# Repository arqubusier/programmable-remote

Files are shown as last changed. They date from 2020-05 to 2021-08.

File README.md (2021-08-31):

# Get project

git clone  --recurse-submodules git@github.com:arqubusier/programmable-remote.git

# Build using docker

    $ cd <project-root>

Build docker image like so:

    $ docker build -t stm32-cpp-bare .

Run the container:

    $ docker run -it --name stm32-cpp-bare -p 4444:4444 -v "$(pwd)":/usr/src/app --privileged -v /dev/bus/usb:/dev/bus/usb stm32-cpp-bare /bin/bash

If you stop the container, you can start it again with:

    $ docker start -a -i stm32-cpp-bare

The project root directory on the host machine and "/usr/src/app" in the container can be used to share data.

## First-time setup

In the container run:

  root@mycontainer $ make -C libopencm3

## Build

In the container run:

  root@mycontainer $ make -C src

## Flashing

This project is currently only tested for the "bluepill" devboard.
In the container run:

  root@mycontainer $ openocd -f bluepill.cfg -c "program src/programmable-remote.elf verify reset exit"

## compile and flash using running openocd server

Start openocd server

  root@mycontainer openocd -f bluepill.cfg
  
Build and flash:

DOES NOT WORK
  root@mycontainer make -C src && echo "program src/programmable-remote.elf verify reset" | telnet localhost 4444
  
  reset halt
  stm32f1x mass_erase 0
  flash write_bank 0 src/programmable-remote.bin 0
  reset halt
  
## Write protection error

Solve using 

  reset halt; stm32f1x unlock 0

## Debug with openocd and gdb

  root@mycontainer gdb-multiarch -tui --eval-command="target remote localhost:3333" src/programmable-remote.elf

## Generate compile_commands.json

  $ make -C src clean
  $ bear make -C src

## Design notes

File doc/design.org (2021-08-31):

* Todo
** TODO Ir sensor wrong orientation
** TODO Ir sensor footprint mark direction
** TODO SWD Silkscreen pin marking
** TODO No dip switch use solder bridge instead
** TODO lower profile crystal
** TODO Reset switch wrong pinout
** TODO Battery holder pads match battery holder placement better
** TODO Battery holder battery too tight
** TODO Transistor swap pins
** TODO Bad ir range
** TODO pcb remote not working with AV reciever
* Design
** General algorihm
Assume protocol has a series of bursts.
For sensing, store length of every burst and space.

*** Determine length of message
Must not confuse message with repeat message.

Timeout: assume time limit for section (burst or space)
< 23.939 ms for NEC2 (All ones)
24/0.005 = 48000

Limit on number of sections.

** interfaces summary

See schema

** Programs
4 programs 0-9
10 commands
100 segments 16 bit (How are these stored? 32-bit aligned?)
4*1000*2B = 8 KB
Packing could reduce it

** Recording

Use a timer, diff-timer, to measure pulse lengths.
When triggered follow sensing algorithm based on state machine.
Compare elapsed duration since previous trigger and evaluate expected duration based on current state.
If evaluation fails, goto backoff state of algorithm.
Restart timer.

Detect overlflow by checking UIF bit in TIMx_SR, URS bit must be set correctly.

** Timers

- inter segment (inter command) tim5
- carrier tim4, tim4_ch1  pb6 (remap==0)
- debounce tim3

Total time = (counter*prescaler)/SYSCLK frequency
prescaler = (total time*SYSCLK frequency)/countermax

*** Pulse lengths
- Sequence timer
- command timer (maybe reprogram sequence timer on the fly)
- carrier timer

16bit prescaler
16bit counter

16bit counter 2^16-1 = 65535

RCC 72MHz
ABP1 Max 36Mhz

*** Command input handling

min period 9ms (start bit)
max period Nec2, address all ones: 
9000 + 4500 + 16*2250 + 16*(2250+1120)/2 + 560 [us] = 77020 [us] ~ 77 ms

choose value closer to longest required pulse: 9 ms (NEC)
20 ms.

prescaler = 20ms * 72 MHz/65535 = 21.97
period = 22/72Mhz

set prescaler to 22 -> timeout slightly larger than 20ms
65535*(22/72Mhz) = 0.0200245833... s

1st = 9000 us ~ 29455
2nd = 4500 us ~ 14727
short pulse = 560 us, 560e-6/(22/(72e6)) = 560*72/22 ~ 1833 counter
long pulse = (2250-560) us = 1690,  1690*72/22 ~ 5531 counter

Start timer when ir sensor goes low. Then stop when goes high and save value.
Interrupt on sensing pin.
Start timer on falling edge interrupt, Stop timer and read value on rising endge interrupt.

*** Carrier frequency

To keep the phase of the carrier pulse, start timer at beginning of command and keep it running until the end.
Control the carrier pulse output by enabling/disabling the output.
A separate timer is used for the carrier pulse.

38kHz ca 0.23 us
Use toggle output of timer.
The output toggles at double frequency 76Khz.
Use approximation for the period
0.013157894736842105263157894736842105263157894736842105263... ms
13.157894736842105263157894736842105263157894736842105263... us

use no prescaler for max resolution
0.0000131578947*72000000 = 947.3684184
947/72000000 = 1.3152777777777778e-05

Use upcounting mode TIMx_CR1, TIMx_CR2
Use continuous mode (not One-pulse mode)
autoreload 947 TIMx_ARR, TIMx_CR1, TIMx_CR2
compare 947 TIMx_CCRx, disable preload OCxPE bit in the TIMx_CCMRx register
output toggle mode, OCxM bits in the TIMx_CCMRx register (OCxM=011)
disable interrupt (CCXIE bit in the TIMx_DIER register)
disable dma (CCxDE bit in the TIMx_DIER register)
**** TODO Use TIM1 for higher precision? 72Mhz vs 36Mhz
     Cannot get it to work.
works for TIM2 and TIM3.
Tim1 uses ABP2 Different config needed?
Tim1 has extra features? which? different config needed?

*** Button debounce timer

bounce ca 5ms

SYSCLK 36 mhz (?)   

prescaler = 5ms * 72 MHz/65535 = 5.4...   

set prescaler to 6 ->
counter = 5ms * 72 MHz/6 = 60'000

*** Transmit inter command

Reuse Command timer.

set prescaler to 23 -> timeout approx 110 ms
65535*(121/72Mhz) = 0.11013520833333335 s

If this time is too short, a receiving device might ignore it and/or think it is part and/or think it is part of the previous command.

Test appropriate value.

** Buttons

0-9
ok
back

* Knowledge
** IR Protocols
diode frequencies:

longest pulse: 9ms (NEC)
*** PWM-based

http://irdb.tk/find/

**** NEC
38kHz
8 bit address, 8 bit inverse address, 8bit command, 8bit inverse command
https://techdocs.altium.com/display/FPGA/NEC+Infrared+Transmission+Protocol
**** NEC2
38kHz
https://www.sbprojects.net/knowledge/ir/nec.php
16 bit address, 16bit command

**** Epson projector
38kHz
Protocol NEC2
**** Harman Kardon
38kHz
Harman Kardon Receivers: Protocol Emerson device 40 subdevice -1
Harman Kardon Receivers: Protocol NEC device 128 subdevice 112
Harman Kardon Receivers: Protocol NEC1 device 4 subdevice -1
Harman Kardon Receivers: Protocol NEC1 device 128 subdevice 112
Harman Kardon Receivers: Protocol NEC1 device 130 subdevice 114
Harman Kardon Receivers: Protocol NEC1 device 132 subdevice 66
Harman Kardon Receivers: Protocol NEC1 device 132 subdevice 116
Harman Kardon Receivers: Protocol NEC1 device 134 subdevice 118
Harman Kardon Receivers: Protocol NEC2 device 128 subdevice 112
Harman Kardon Receivers: Protocol NEC2 device 130 subdevice 114
Harman Kardon Receivers: Protocol NEC2 device 164 subdevice -1
Harman Kardon Receivers: Protocol Pioneer device 130 subdevice 114
Harman Kardon Receivers: Protocol Pioneer device 161 subdevice -1
Harman Kardon Receivers: Protocol RCA-38 device 7 subdevice -1

** Remotes
*** Harman Kardon
carrier 587 us - 560us

OK 7484 6f90

**** osd menu

0-7   k k k l k k k k  0100  4 
8-15  k k k k k k k l  0001  1
16-23 k k k l k k k k  0100  4
24-31 k l k l k l k k  1110  E
32-39 k k k k k l k l  0011  3
40-47 k l k k k l k k  1010  a
48-55 k l k l k k k k  1100  c
56-63 k k k l k k k l  0101  5

NEC1
OK 0x12 e2 90 6F
18 226

NEC2
OK 0xe212  6F90

*** Epson
carrier 587 us - 625 us
*** OSSC
carrier 562 us - 612 us
** Components
*** Stm32f103c8t6
**** Constraints
***** Memory
stm32f103c8t6

SRAM 10KiB
Flash 64KiB

**** Clock

Three sources: internal, external, pll. Pll uses internal or external as a source and can multiply the frequency.
Max sysclock for internal is 36mHz, max for external is 72 MHz. 

Default seems to be 36mHz -> internal?

*** IR diode
*** IR receiver
https://www.electrokit.com/uploads/productfile/41015/41015734_-_IR_Receiver_Module.pdf
negative and signal marked on board, middle is vcc 0.4v-4.4v.
**** TSOP382
combined led and "demodulator", turns 38
  
Program ir sequences using sensed signals from existisng remote.
Use a button combination to enter programming mode.
Use the following algorithm to create a program.

DRAW DIAGRAM.
1. Press programming button. leds start flashinsg to indicate programming mode.
   press number to select slot and continue.
2. Press a button on other remote to select command.
   Leds indicate success/failure.
   Use stop sequence to stop.
   The current program will be stored and a default value
3. Enter repeate count. Use reset button to clear. Use confirm button to proceed.
4. Press stop sequence to finish, otherwise Go to step 2

Sens signals from remote when programming.

*** Serial EEPROM
*** Buttons
*** display
*** leds
** IR NEC Timings

Bit Pulse length 560us



./necsequence.png

Max duration 100 ms, repeat distance.
Min 560us

* DONE Weird timings_ values                                        :ARCHIVE:
prescaler 360:
$96 = {796, 897, 118, 109, 118, 109, 118, 334, 118, 109, 112, 114, 118, 109, 113, 114, 113, 339, 118, 109, 118, 109, 112, 340, 113, 114, 113, 340, 113, 340, 113, 340, 118, 108, 118, 108, 112, 114, 118, 109, 118, 108, 118, 334, 113, 114, 117, 109, 113, 340, 113, 340, 117, 335, 112, 340, 113, 340, 113, 114, 112, 340, 113, 340, 113, 114, 113, 0 <repeats 33 times>}

prescaler 180: 
p timings_
$92 = {577, 797, 235, 214, 235, 215, 225, 676, 234, 215, 235, 215, 235, 215, 234, 215, 224, 676, 235, 216, 234, 215, 225, 676, 234, 216, 224, 677, 225, 676, 224, 677, 234, 215, 235, 216, 234, 215, 235, 215, 235, 215, 224, 676, 235, 215, 235, 215, 224, 676, 224, 676, 224, 677, 224, 676, 224, 676, 235, 216, 224, 676, 224, 676, 235, 215, 224, 0 <repeats 33 times>}

prescaler 100:
$95 = {416, 200, 422, 384, 420, 384, 399, 212, 401, 404, 420, 384, 400, 405, 401, 403, 420, 191, 419, 387, 400, 405, 399, 212, 418, 386, 399, 211, 400, 211, 400, 211, 400, 405, 400, 406, 418, 386, 417, 386, 419, 384, 399, 211, 400, 404, 399, 405, 400, 210, 399, 211, 400, 212, 420, 190, 419, 194, 401, 405, 400, 210, 420, 192, 421, 384, 399, 0 <repeats 33 times>}

Had not set period, so counter was looping to early.
* TODO Synchronize Multiple interrupts and main thread.             :ARCHIVE:

Use interrupt priorities.

We have main thread and a number of interrupts:

- input_ir exti input_handler
- delay timer
- output_ir timer

- button exti
  - select between input/output modes.
    - only enable either:
      - output_ir timer and delay timer or
      - input_ir timer and delay timer

set delay timer lower prio, can still be tail-chained

delay timer can come first, then be preempted

* TODO Button circuit                                               :ARCHIVE:
10 buttons

** direct conncetion: 10 gpio internal pulldown, 1 common high connection.
*** TODO interrupt handling
possible to use same isr for multiple gpios?

Use exti1-10 for each button, one isr per button.

debouncing: use general synchronization method, interrupt disabling.
** Keypad
** Swithes

* Problems
** TODO Figure out why this basic calculation yields wrong result

  uint32_t b  = (rcc_apb1_frequency * 2);

**TODO Hangs in constructor : ARCHIVE :

    in statemachine.hpp : 52 command_index_{0},
    program_index_{program_index} {}

calls memcpy and hangs in loop 0x08004198-0x080041a2

Dump of assembler code for function memcpy:
   0x0800418a <+0>:	add	r2, r1
;
r0 0x200000d8 536871128;
r1 0x200027e8 536881128;
r2 0x20004fd4 536891348 0x0800418c < +2 > : cmp r1,
    r2 = > 0x0800418e < +4 > : add.w r3, r0, #4294967295;
0xffffffff destination address;
r3 0x200000d7 536871127 0x08004192 < +8 > : bne.n 0x8004196 < memcpy + 12 > ;
r4 0x200000d8 536871128;
lr 0x80019fd 134224381 0x08004194 < +10 > : bx lr 0x08004196 < +12 > : push {
  r4, lr
}
0x08004198 < +14 > : ldrb.w r4, [r1], #1;
postincrement r1 0x0800419c < +18 > : cmp r1, r2 0x0800419e < +20 > : strb.w r4,
    [ r3, #1 ] !;
preincrement r3 0x080041a2 < +24 > : bne.n 0x8004198 < memcpy + 14 >
    0x080041a4 < +26 > : pop{r4, pc}

                         memcpy 536891348 -
                         536881128 10220 elements 2 * 100 * 10 *
                             5

                             does it fit in destination
    ? ;
r3 0x200000d7 536871127 536871127 +
    10219 = 536881346 = 0x200028c2 0x200000d7 - 0x200028c2 > 0x200027e8

                        too many bytes
    ? src,
    return addresses cause problems
    ?

    hard_faults,
    CFSR == 0x20000 user fault,
    invalid state.no idea why.

        (gdb)p
        / x pc $22 = 0x8001ae9 Uneven address
    ? ? ?

        ***Soloution Redesign,
    global variable,
    or pass around reference to common state instead of composition.

            global variable
            + easy to implement + can still change it in test
            - hidden state **Following hangs
    : ARCHIVE
    :

    using Buttons = std::array<util::Io, kNumButtons>;
// global variable
// note double outer braces
// if single outer braces are used the problem disappears
constexpr Buttons buttons{{
    {GPIOA, GPIO1},
}};

for (const auto &button : buttons) {
  uint32_t exti{util::GetExtiIrqn(button.pin_).value()};
}

** Debounce timer works for tim3 but not tim5                       :ARCHIVE:

commit 8a56048e89eca8753037eba329801153a9f771ca

*** Solution

stm32f103c8t6 only has timers 1-4

* Example

** osd/menu harman cardon

 {
  prog_i = 0, cmd = {
    data_ = {_M_elems = {29462, 14780, 1844, 1841,
                         1838,  1841,  1836, 5550,
                         1844,  1839,  1838, 1838,
                         1836,  1841,  1837, 1841,
                         1833,  5548,  1845, 1842,
                         1839,  1840,  1837, 5549,
                         1838,  1841,  1836, 5551,
                         1839,  5548,  1838, 5551,
                         1840,  1839,  1835, 5548,
                         1839,  5554,  1837, 5548,
                         1842,  1841,  1834, 5553,
                         1836,  5552,  1835, 5551,
                         1841,  1843,  1835, 1842,
                         1838,  1840,  1836, 1839,
                         1834,  5555,  1839, 1837,
                         1838,  1840,  1836, 1842,
                         1833,  5549,  1837, 0 < repeats 33 times > }},
    size = 67
  }

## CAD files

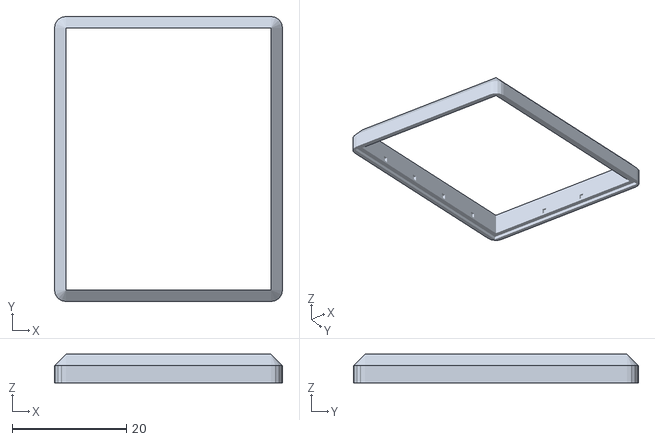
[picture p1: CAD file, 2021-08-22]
case/xcsg/remote.stl
40.0 x 50.0 x 5.00

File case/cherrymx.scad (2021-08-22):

switch_side_outer=19.1;
switch_sep = 19.05;
switch_side_inner=13.6;
switch_height=3;
plate_thick_d=0;
plate_thick=1.5 + plate_thick_d;
inset_h=switch_height - plate_thick;
inset_w=5;
inset_d=0.7;
outset_d=0.2;
switch_pcb_to_plate_top = 4.7;

module inset() {
    translate([0, switch_side_inner/2 + inset_d/2, (switch_height)/2 -inset_h - plate_thick])
        cube([inset_w, inset_d, 2*inset_h], center=true);
}

module outset() {
    translate([0, switch_side_inner/2 - outset_d/2, switch_height/2-plate_thick/2])
        difference() {
            cube([inset_w,outset_d,plate_thick], center=true);
            cube([inset_w-2.5,outset_d,plate_thick], center=true);
        }
}

module switch_pos(height=switch_height, center_height=false) {
    if (center_height) {
        cube([switch_side_outer, switch_side_outer, height], center=true);
    } else {
        translate([0, 0, height/2])
            cube([switch_side_outer, switch_side_outer, height], center=true);
    }
}

module SwitchPos2D() {
       square(switch_side_outer, center=true);
}

module SwitchNeg2D() {
       square(switch_side_inner, center=true);
}

module switch_neg_cube() {
    translate([0,0,switch_height/2])
        cube([switch_side_inner, switch_side_inner, switch_height], center=true);
}

module switch_neg(switch_height_mult=1) {
    translate([0,0,switch_height/2]) {
        difference() {
            cube([switch_side_inner, switch_side_inner, switch_height_mult*switch_height], center=true);
            *outset();
            *mirror([0,1,0])
                outset();
        }
        inset();
        mirror([0,1,0])
            inset();
    }
}

module switch(side_outer=switch_side_outer) {
    difference() {
        switch_pos(side_outer);
        switch_neg(1);
    }
}

module keycap(center=true) {
  cube([18, 18, 8.5],center=center);
}

function switch_corner_outer(offset, corner) = offset +
  ( (corner == "ne" ? [switch_side_outer/2, switch_side_outer/2, 0] :
     (corner == "se" ? [switch_side_outer/2, -switch_side_outer/2, 0] :
      (corner == "sw" ? [-switch_side_outer/2, -switch_side_outer/2, 0] :
       ([-switch_side_outer/2, switch_side_outer/2, 0])))) );

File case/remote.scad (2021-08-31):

include <cherrymx.scad>

$fn = 20;
module TriangleRightAngle(w, h) {
    polygon([[0,0], [w,0], [w,h]]);
}

module BoxChamfer(w,l,h,chamfer) {
    translate([chamfer,chamfer,0]) {
        minkowski() {
            cube([w-2*chamfer,l-2*chamfer,h-2*chamfer]);
            union() {
                translate([0,0,chamfer])
                    cylinder(h=chamfer, r1=chamfer, r2=0);
                cylinder(h=chamfer, r1=0, r2=chamfer);
            }
        }
    }
}

module BoxChamferTop(w,l,h,chamfer) {
    translate([chamfer,chamfer,0]) {
        minkowski() {
            cube([w-2*chamfer,l-2*chamfer,h-chamfer]);
            cylinder(h=chamfer, r1=chamfer, r2=0.4);
        }
    }
}

module BoxFilletSides(x, y, z, chamfer) {
    translate([chamfer,chamfer,0]) {
        minkowski() {
            cube([x-2*chamfer,y-2*chamfer,z-2*chamfer]);
            cylinder(h=chamfer, r=chamfer);
        }
    }
}


battery_y = 44+.5;
battery_d = 10;
battery_z = battery_d + 1.1;
battery_clip_x = 6.9 + .2;
battery_clip_y = .5 + .2;
battery_clip_plus_y = 2;
battery_clip_wall_thick = .8;
battery_clip_holder_y = battery_clip_plus_y + 2*battery_clip_wall_thick;
battery_holder_y = battery_y + 2*battery_clip_holder_y;
battery_holder_side_thick = 1;
battery_holder_x = 2*battery_d + battery_holder_side_thick;

module BatteryClipHolderNegative() {
    translate([0,.1,0]){
            rotate([90, 0, 0])
                cylinder(h= battery_clip_wall_thick+.2, d=battery_clip_x - 1);
            translate([battery_d, 0, 0])
                rotate([90, 0, 0])
                    cylinder(h= battery_clip_wall_thick+.2, d=battery_clip_x - 1);
    }
    
    translate([-battery_clip_x/2, -battery_clip_wall_thick-battery_clip_y, -battery_clip_x/2])
    {
        cube([battery_clip_x, battery_clip_y, battery_d]);
        translate([battery_d,0,0])
            cube([battery_clip_x, battery_clip_y, battery_d]);
    }
    
    translate([-battery_clip_x/2, -battery_clip_wall_thick-battery_clip_y, -battery_d/2]) {
        cube([battery_d + battery_clip_x, battery_clip_y, battery_d]);
    }
    
    translate([-battery_clip_y/2, -battery_clip_holder_y - battery_clip_wall_thick, -battery_clip_y + battery_d/2-1]) {
        cube([battery_clip_y,battery_clip_holder_y,battery_clip_y+1]);
        translate([battery_d, 0, 0])
            cube([battery_clip_y,battery_clip_holder_y,battery_clip_y+1]);
    }
    
    
    translate([-(battery_clip_x - 1)/2,-battery_clip_wall_thick - .1,0]) {
        cube([battery_clip_x - 1, battery_clip_wall_thick + .2, battery_d/2+1]);
        translate([battery_d, 0, 0])
            cube([battery_clip_x - 1, battery_clip_wall_thick + .2, battery_d/2+1]);
    }
}

module BatteryHolderNegative() {
    translate([battery_d/2, battery_clip_holder_y, battery_d/2]){
        rotate([-90, 0, 0])
            #cylinder(battery_y,d=battery_d);
        translate([battery_d, 0, 0])
            rotate([-90, 0, 0])
                cylinder(battery_y,d=battery_d);
        BatteryClipHolderNegative();
        translate([battery_d, battery_y, 0])
            rotate([0,0,180])
                BatteryClipHolderNegative();
     }

    translate([0,battery_clip_holder_y,battery_d/2])
        cube([2*battery_d, battery_y, battery_d]);
}

plate_thick = 2;
wall_thick = 2.7;
chamfer = 1.6;

pcb_y = 72.3;
pcb_x = switch_sep*2+ 2*2.7;
pcb_z = .8;
pcb_pos_z = 3.5 + plate_thick;
pcb_pos_y = wall_thick + battery_holder_y + 1;

switch_row0_pos_y = pcb_pos_y + 9 + switch_sep/2;


width_outer = pcb_x + 2*wall_thick;
width_inner = width_outer - 2*wall_thick;
height_high_inner = battery_z + plate_thick;
height_high_outer = height_high_inner + wall_thick;
height_low_outer = pcb_pos_z + pcb_z + 5.1;
height_low_inner = height_low_outer - wall_thick;

box1_outer_y = switch_row0_pos_y - switch_sep/2;
box1_inner_y = box1_outer_y - 2*wall_thick;

box2_outer_y = 3*switch_sep + 4*chamfer;
box2_inner_y = box2_outer_y - 2*wall_thick;
box2_pos_y = box1_outer_y - 2*chamfer;
box2_pos = [0, box2_pos_y, 0];

box3_inner_y = 3.8;
box3_outer_y = box3_inner_y + 2*wall_thick;
box3_pos = box2_pos + [0, box2_outer_y - 2*chamfer, 0];

outer_z = box2_pos_y+ box2_outer_y + box3_outer_y - 2*chamfer;
inner_z = outer_z - 2*wall_thick;

plate_lip_z = .6;
plate_lip_x = width_inner +2*.5;
plate_lip_y = inner_z +2*.5;

module BatteryHolder() {
    
    translate([wall_thick + battery_holder_x, wall_thick-battery_clip_wall_thick, height_high_inner])
        rotate([0,180,0])
        difference() {
            cube([battery_holder_x, battery_holder_y, battery_d]);
            translate([battery_holder_side_thick, 0, 0])
            BatteryHolderNegative();
        }
}

module ShellPositive() {
        BoxChamfer(width_outer, box1_outer_y, height_high_outer, chamfer);
        translate(box2_pos)
            BoxChamfer(width_outer, box2_outer_y, height_low_outer, chamfer);
        translate(box3_pos)
            BoxChamfer(width_outer, box3_outer_y, height_high_outer, chamfer);
}

module ShellNegative() {
    translate([wall_thick, wall_thick, -.1]) {
        BoxChamferTop(width_inner, box1_inner_y, height_high_inner, chamfer);
        translate(box2_pos + [0, -wall_thick*2, 0])
            BoxChamferTop(width_inner, box2_inner_y+wall_thick*4, height_low_inner, chamfer);
        translate(box3_pos)
            BoxChamferTop(width_inner, box3_inner_y, height_high_inner, chamfer);
    }
    
    translate([wall_thick, switch_row0_pos_y - switch_side_inner/2-7-1.2, pcb_pos_z + pcb_z])
        cube([width_inner, 7, 4]);
    translate([wall_thick, switch_row0_pos_y +2*switch_sep+ switch_side_inner/2+1.2, pcb_pos_z + pcb_z])
        cube([width_inner, 7, 4]);
}

niche_pos_z = 1.6;
niche_x = 3.2;
niche_y = 1.2;
niche_z = 1.2;
module Niche() {
    translate([0,0,niche_pos_z+niche_z/2])
        cube([niche_x, niche_y, niche_z], center=true);
}

module PlaceNiches() {
    nxs = [-9, 9];
    for (x = nxs) {
        translate([width_outer/2+x,wall_thick-niche_y/2+.1,0]) {
            rotate([0,0,180])
                children();
            translate([0, inner_z + niche_y -.2, 0])
                children();
        }
    }
    
    nys = [-45,-25, 0, 25, 45];
    for (y = nys) {
        translate([wall_thick-niche_y/2+.1,y+outer_z/2,0]) {
            rotate([0,0,90])
                children();
            translate([width_inner-.2+niche_y, 0, 0])
                rotate([0,0,-90])
                    children();
        }
    }
}

hook_x = niche_x - .2;
hook_y = niche_y;
hook_z = niche_z - .2;
module Hook() {
    translate([hook_x/2, -hook_y/2 -.2, niche_pos_z])
       rotate([0,-90,0])
        linear_extrude(hook_x)
            polygon([[0, 0], [hook_y, 0], [0,hook_z]]);
}




module Plate(clearance=0) {
    PlaceNiches()
        Hook();
    
    translate([wall_thick-clearance, wall_thick-clearance, 0])
        cube([width_inner+2*clearance, inner_z+2*clearance, plate_thick+clearance]);
   
    translate([wall_thick-.5-clearance, wall_thick -.5-clearance, 0])
        cube([plate_lip_x+2*clearance, plate_lip_y+2*clearance, plate_lip_z+clearance]);
}



ir_tx_x = 3.4;
ir_tx_rel_x = -3.8-ir_tx_x;
ir_rx_x = 6.6;
ir_rx_rel_x = 3.5;
module SensorHoles() {
    translate([width_outer/2, 2*chamfer + outer_z-1*wall_thick, pcb_pos_z + pcb_z]) {
        translate([ir_tx_rel_x, -.1, 0])
            rotate([90, 0, 0])
                BoxFilletSides(ir_rx_x, 2, 4, .5);
        translate([ir_rx_rel_x, 0, ir_tx_x/2])
            rotate([90, 0, 0])
                cylinder(h = 10, d=ir_tx_x);
        
    }
    led_hole_z = 20;
    led_hole_x = 2;
    #translate([width_outer/2+-led_hole_x/2, pcb_pos_y+pcb_y-3.4, height_high_outer - led_hole_z -.1]) {
        translate([-8.2,0,0])
            BoxFilletSides(led_hole_x,led_hole_x,led_hole_z,.5);
        translate([-10.8,0,0])
            BoxFilletSides(led_hole_x,led_hole_x,led_hole_z,.5);
    }  
}

module SwitchHoles() {
    translate ([width_outer/2-switch_sep/2, switch_row0_pos_y, height_low_outer - switch_height])
        for (col = [0:1]) {
            for (row = [0:2]) {
                translate([col*switch_sep, row*switch_sep, 0])
                    switch_neg(3);
            }
        }
}

module Pcb() {
    translate([wall_thick,pcb_pos_y,pcb_pos_z]) 
        cube([pcb_x, pcb_y, pcb_z]);
}

module Shell() {
    difference() {
        union() {
            difference() {
                ShellPositive();
                ShellNegative();
            }
            BatteryHolder();
        }

        SensorHoles();
        SwitchHoles();
        Plate(.2);
        PlaceNiches()
            Niche();
    }
}

//Shell();
//Pcb();
Plate();

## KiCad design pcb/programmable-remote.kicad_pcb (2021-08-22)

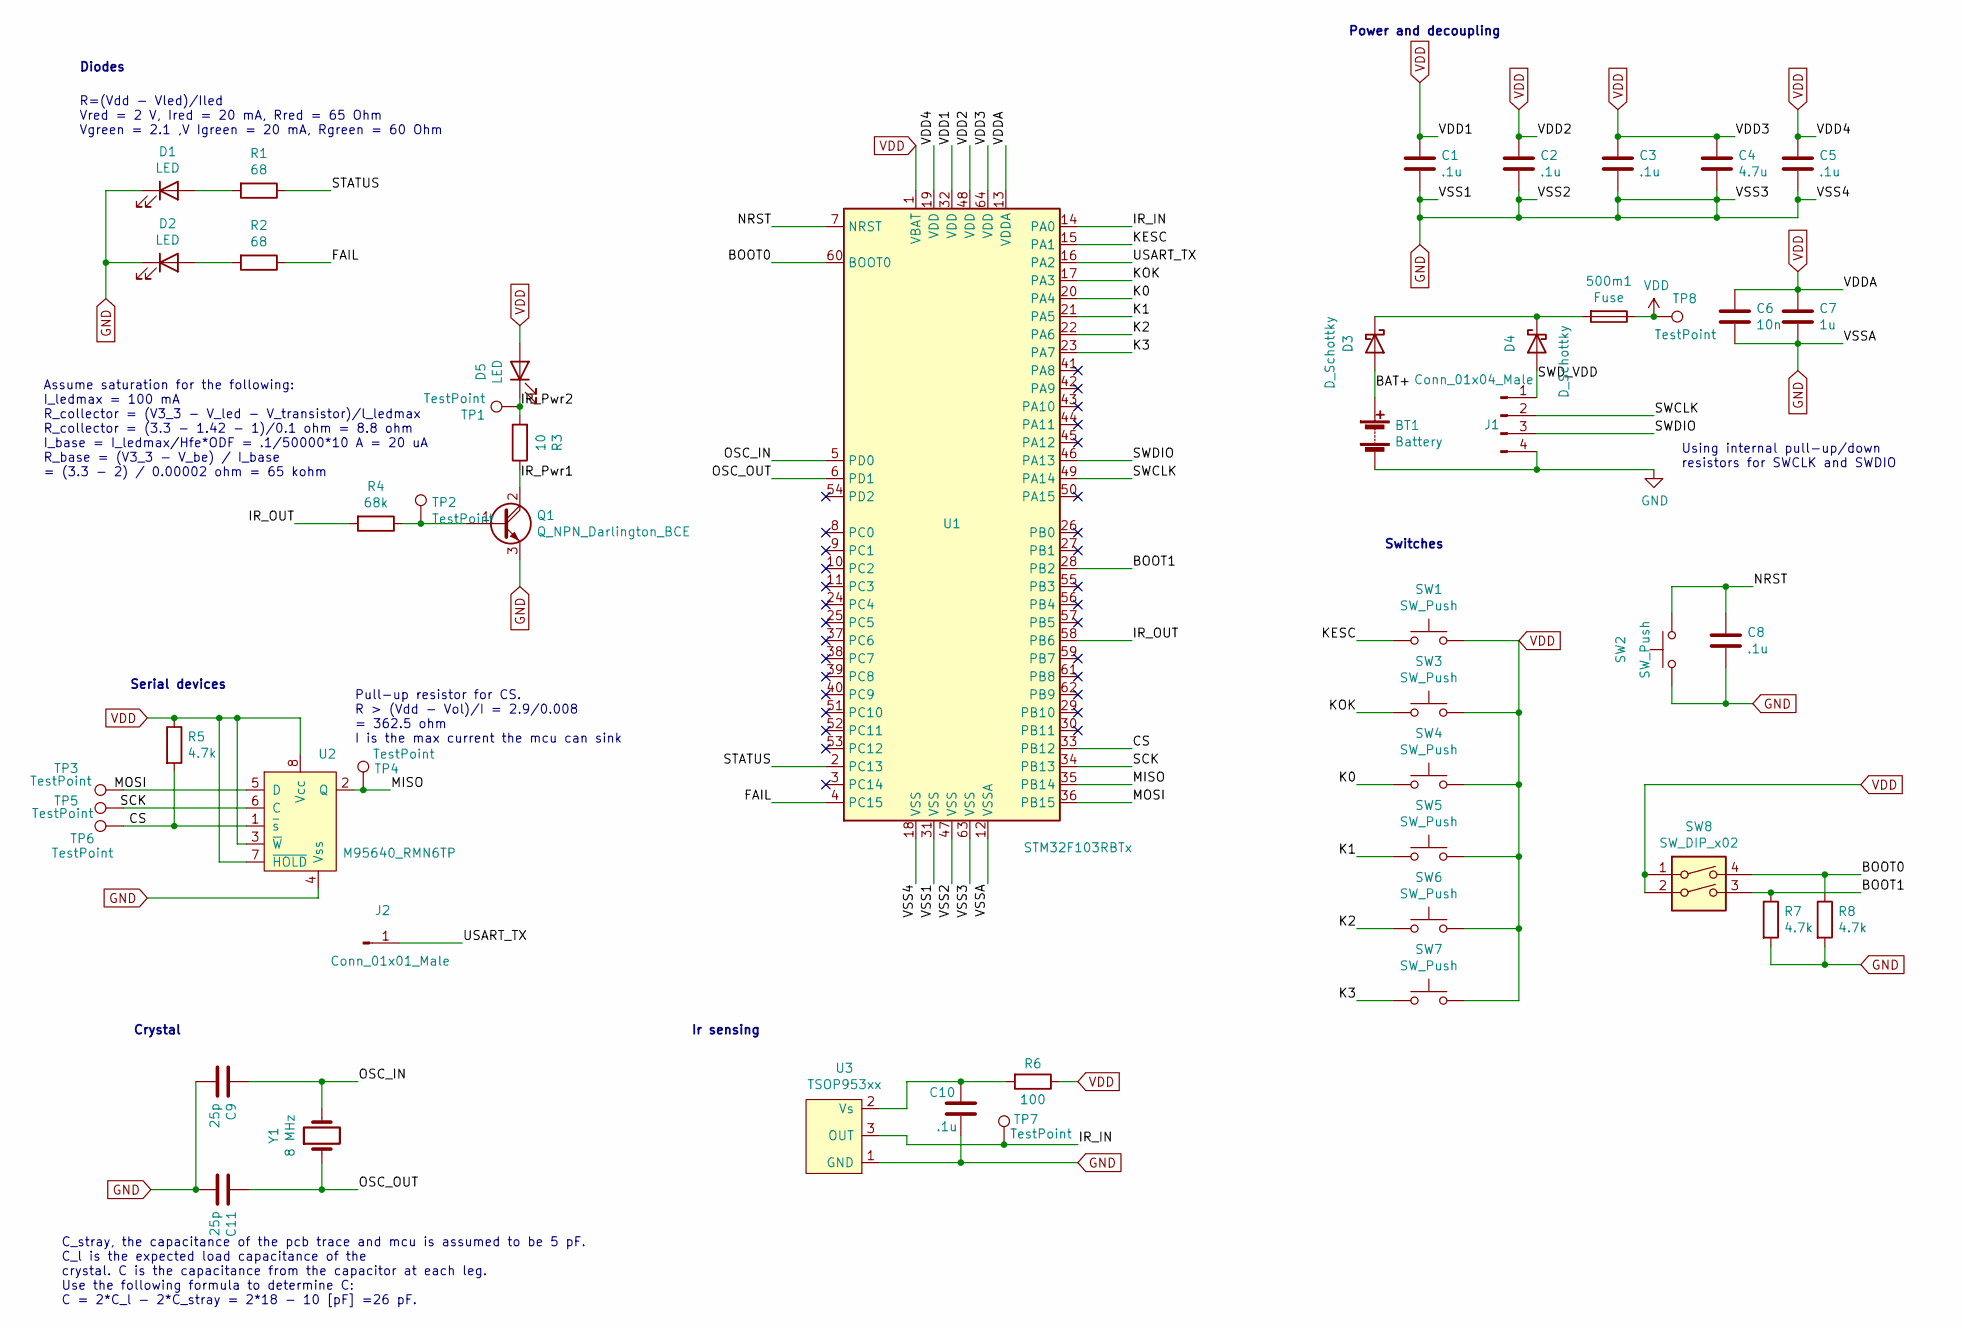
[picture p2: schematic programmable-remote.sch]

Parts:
500m1: Fuse; Fuse_0603_1608Metric_Pad1.05x0.95mm_HandSolder
BT1: Battery
C1, C2, C3, C5, C8, C10: .1u; C_0603_1608Metric_Pad1.08x0.95mm_HandSolder
C4: 4.7u; C_0603_1608Metric_Pad1.08x0.95mm_HandSolder
C6: 10n; C_0603_1608Metric_Pad1.08x0.95mm_HandSolder
C7: 1u; C_0603_1608Metric_Pad1.08x0.95mm_HandSolder
C9, C11: 25p; C_0603_1608Metric_Pad1.08x0.95mm_HandSolder
D1, D2: LED; C_0805_2012Metric_Pad1.18x1.45mm_HandSolder
D3, D4: D_Schottky; D_1206_3216Metric_Pad1.42x1.75mm_HandSolder
D5: LED; LED_D3.0mm_IRGrey
J1: Conn_01x04_Male; PinHeader_1x04_P2.54mm_Vertical
J2: Conn_01x01_Male; PinHeader_1x01_P2.54mm_Vertical
Q1: Q_NPN_Darlington_BCE; TSOT-23_HandSoldering
R1, R2: 68; R_0603_1608Metric_Pad0.98x0.95mm_HandSolder
R3: 10; R_0603_1608Metric_Pad0.98x0.95mm_HandSolder
R4: 68k; R_0603_1608Metric_Pad0.98x0.95mm_HandSolder
R5, R7, R8: 4.7k; R_0603_1608Metric_Pad0.98x0.95mm_HandSolder
R6: 100; R_0603_1608Metric_Pad0.98x0.95mm_HandSolder
SW1, SW3, SW4, SW5, SW6, SW7: SW_Push; SW_Cherry_MX_1.00u_PCB
SW2: SW_Push; SW_PTS526
SW8: SW_DIP_x02; SW_2LP
TP1, TP2, TP3, TP4, TP5, TP6, TP7, TP8: TestPoint; TestPoint_harwin_S2761-46R
U1: STM32F103RBTx; LQFP-64_10x10mm_P0.5mm
U2: M95640_RMN6TP; SOIC-8_3.9x4.9mm_P1.27mm
U3: TSOP953xx
Y1: 8 MHz; Crystal_ABLS-8.000MHZ-B4-T

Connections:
/BAT+: BT1.1 (+), D3.2 (A)
/BOOT0: R8.1, SW8.4, U1.60 (BOOT0)
/BOOT1: R7.1, SW8.3, U1.28 (PB2)
/CS: R5.2, TP6.1, U1.33 (PB12), U2.1 (~s)
/FAIL: R2.1, U1.4 (PC15)
/IR_IN: TP7.1, U1.14 (PA0), U3.3 (OUT)
/IR_OUT: R4.2, U1.58 (PB6)
/IR_Pwr1: Q1.2 (C), R3.1
/IR_Pwr2: D5.1 (K), R3.2, TP1.1
/K0: SW4.1, U1.20 (PA4)
/K1: SW5.1, U1.21 (PA5)
/K2: SW6.1, U1.22 (PA6)
/K3: SW7.1, U1.23 (PA7)
/KESC: SW1.1, U1.15 (PA1)
/KOK: SW3.1, U1.17 (PA3)
/MISO: TP4.1, U1.35 (PB14), U2.2 (Q)
/MOSI: TP3.1, U1.36 (PB15), U2.5 (D)
/NRST: C8.1, SW2.2, U1.7 (NRST)
/OSC_IN: C9.1, U1.5 (PD0), Y1.2
/OSC_OUT: C11.1, U1.6 (PD1), Y1.1
/SCK: TP5.1, U1.34 (PB13), U2.6 (C)
/STATUS: R1.1, U1.2 (PC13)
/SWCLK: J1.2, U1.49 (PA14)
/SWDIO: J1.3, U1.46 (PA13)
/SWD_VDD: D4.2 (A), J1.1
/USART_TX: J2.1, U1.16 (PA2)
GND: BT1.2 (-), C1.2, C2.2, C3.2, C4.2, C5.2, C6.2, C7.2, C8.2, C9.2, C10.2, C11.2, D1.1 (K), D2.1 (K), J1.4, Q1.3 (E), R7.2, R8.2, SW2.1, U1.12 (VSSA), U1.18 (VSS), U1.31 (VSS), U1.47 (VSS), U1.63 (VSS), U2.4 (Vss), U3.1 (GND)
unnamed: 500m1.2, D3.1 (K), D4.1 (K)
unnamed: C10.1, R6.2, U3.2 (Vs)
unnamed: D1.2 (A), R1.2
unnamed: D2.2 (A), R2.2
unnamed: Q1.1 (B), R4.1, TP2.1
VDD: 500m1.1, C1.1, C2.1, C3.1, C4.1, C5.1, C6.1, C7.1, D5.2 (A), R5.1, R6.1, SW1.2, SW3.2, SW4.2, SW5.2, SW6.2, SW7.2, SW8.1, SW8.2, TP8.1, U1.1 (VBAT), U1.13 (VDDA), U1.19 (VDD), U1.32 (VDD), U1.48 (VDD), U1.64 (VDD), U2.3 (~W), U2.7 (~HOLD), U2.8 (Vcc)

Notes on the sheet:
R=(Vdd - Vled)/Iled Vred = 2 V, Ired = 20 mA, Rred = 65 Ohm Vgreen = 2.1 ,V Igreen = 20 mA, Rgreen = 60 Ohm
Power and decoupling
Diodes
Switches
Crystal
Ir sensing
C_stray, the capacitance of the pcb trace and mcu is assumed to be 5 pF. C_l is the expected load capacitance of the crystal. C is the capacitance from the capacitor at each leg. Use the following formula to determine C: C = 2*C_l - 2*C_stray = 2*18 - 10 [pF] =26 pF.
Serial devices
Assume saturation for the following: I_ledmax = 100 mA R_collector = (V3_3 - V_led - V_transistor)/l_ledmax R_collector = (3.3 - 1.42 - 1)/0.1 ohm = 8.8 ohm I_base = I_ledmax/Hfe*ODF = .1/50000*10 A = 20 uA R_base = (V3_3 - V_be) / I_base = (3.3 - 2) / 0.00002 ohm = 65 kohm
Pull-up resistor for CS. R > (Vdd - Vol)/I = 2.9/0.008 = 362.5 ohm I is the max current the mcu can sink
Using internal pull-up/down resistors for SWCLK and SWDIO

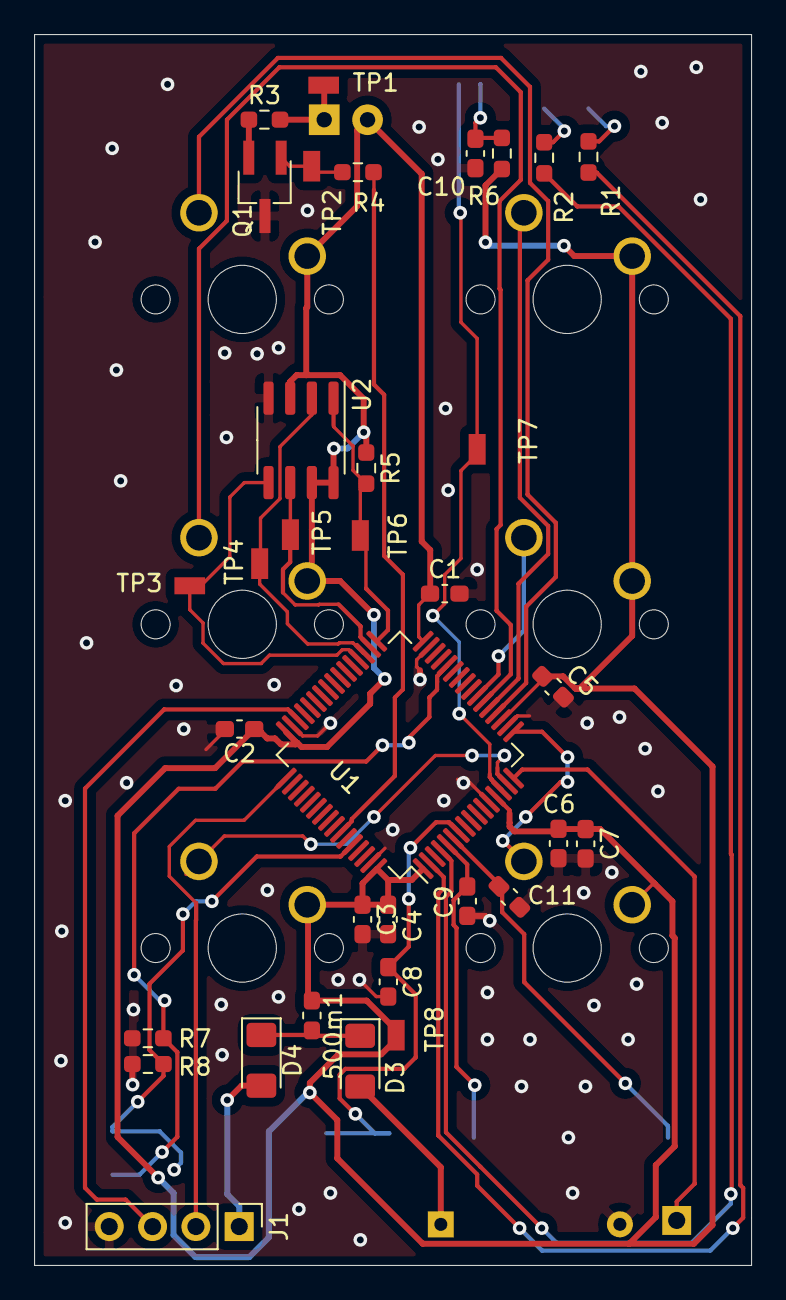
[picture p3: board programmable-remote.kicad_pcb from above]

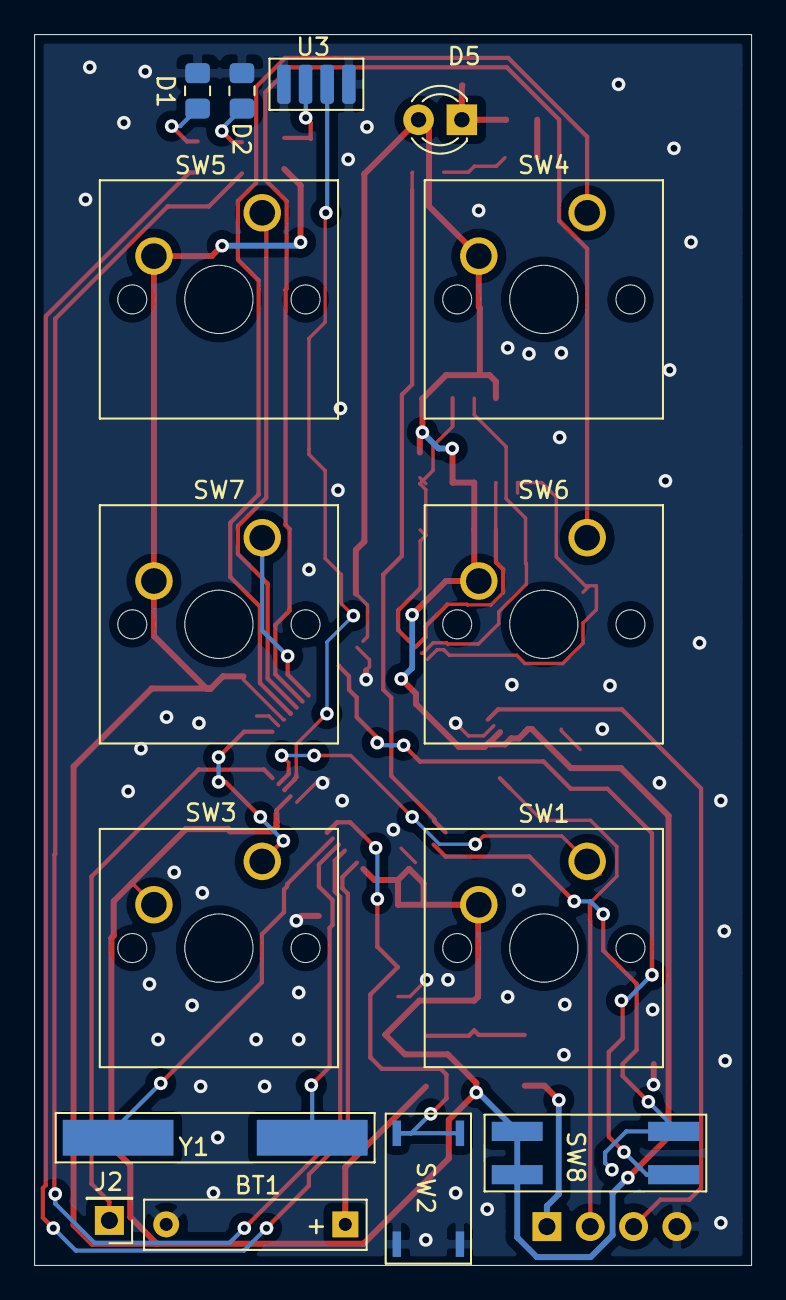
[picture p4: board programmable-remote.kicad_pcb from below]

Board: 2 copper layers, 42.0 x 72.2 mm, 49 parts (15 on the bottom side), 33 nets.

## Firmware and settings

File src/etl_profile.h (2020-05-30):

// configure etl for the used platform.
#ifndef ETL_PROFILE
#define ETL_PROFILE

#define ETL_TARGET_DEVICE_ARM
#define ETL_TARGET_OS_NONE
#define ETL_CPP11_SUPPORTED 1
#define ETL_CPP14_SUPPORTED 1
#define ETL_CPP17_SUPPORTED 0
#define ETL_CPP20_SUPPORTED 0
#define ETL_NO_NULLPTR_SUPPORT 0
#define ETL_NO_LARGE_CHAR_SUPPORT 0
#define ETL_CPP11_TYPE_TRAITS_IS_TRIVIAL_SUPPORTED 1
#define ETL_NO_STL

#endif // ETL_PROFILE

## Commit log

2020-04-19 Adapted libopencm3 template
    [bluepill.cfg]
2020-04-19 Added interrupt, problems triggering consitently.
2020-04-26 Added working timer example and fixed interrupt issue.
2020-04-27 Trying to output timer WIP.
2020-04-27 Output from timer on pin :)
2020-05-02 Input interrupt.
2020-05-03 Command timer timing correct.
2020-05-10 Refactoring. Problem with EXTI interrupt not triggering a second time.
2020-05-11 restarting from timer example.
2020-05-13 Timer interrupt too soon.
2020-05-16 OutputHandler interrupt triggers.
2020-05-30 Statemachine prototype.
2020-07-21 Fixed compliation issues for device, issue with ram size.
2021-05-19 Debounce timer works for tim3 but not tim5.
2021-05-20 debounce timer correct behaivour.
2021-05-23 Prototype debouncing, not tested.
2021-05-26 Consume button bounce interrutps. Problem with consecutive presses.
2021-06-01 six buttons.
2021-06-01 Template buttons.
2021-06-06 move led pin.
2021-06-13 Fixed bug in button_setup and delay
2021-06-13 All buttons working :)
2021-06-13 missing interrupt flag clearing.
2021-06-20 Prototype rx
2021-08-03 Tx statemachine prototype.
2021-08-03 Cannot get interrupt from tim2.
2021-08-04 Tim2 interrupting.
2021-08-07 Added schematic.
    [programmable-remote.kicad_pcb, programmable-remote.sch]
2021-08-08 Initial schematic done.
    [programmable-remote.sch]
2021-08-08 Fix drc errors.
    [programmable-remote.sch]
2021-08-08 Started layout.
    [programmable-remote.kicad_pcb, programmable-remote.sch]
2021-08-11 signals routed
    [programmable-remote.kicad_pcb, programmable-remote.sch]
2021-08-11 ground pour added
    [programmable-remote.kicad_pcb]
2021-08-13 Pcb 1.0
    [programmable-remote.kicad_pcb, programmable-remote.sch]
2021-08-21 Started with case.
    [remote.stl]
2021-08-22 minor change
    [programmable-remote.kicad_pcb]
2021-08-22 Restarted case with OpenScad.
    [cherrymx.scad, remote.scad]
2021-08-22 More work on case.
    [remote.scad]
2021-08-23 Adjusted case according to pcb.
    [remote.scad]
2021-08-24 Case fixes.
    [remote.scad]
2021-08-31 Various changes.
    [remote.scad]
